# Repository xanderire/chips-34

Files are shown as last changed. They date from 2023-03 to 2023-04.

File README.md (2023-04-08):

# chips-34

Prototype, diodless pcb with minor key stagger and two thumb keys.

This started as a project to learn [Ergogen](https://github.com/ergogen/ergogen) and [KiCad](https://www.kicad.org/)

- Work-in-progress pcb that is under **100mm x 100mm** in order to facilitate a common discounted price for pcb manufactures for small pcbs.
- I do not claim this to be the most efficent or best way to build a keyboard pcb.
- This project is more to have fun and prototype different designs.
- As such I also cannot promise any files in this repo are correct and will work as production files.

---

## BOM

| Components | Amount |
| :--- | :----: |
| Arduino Pro Micro | 2 |
| TRRS-PJ-320A-dual | 2 |
| SPST Tactile Switch | 2 |
| Kailh MX Hotswap Sockets | 34 |
| MX Switches | 34 |
| MX Keycaps | 34 |

---

## Images

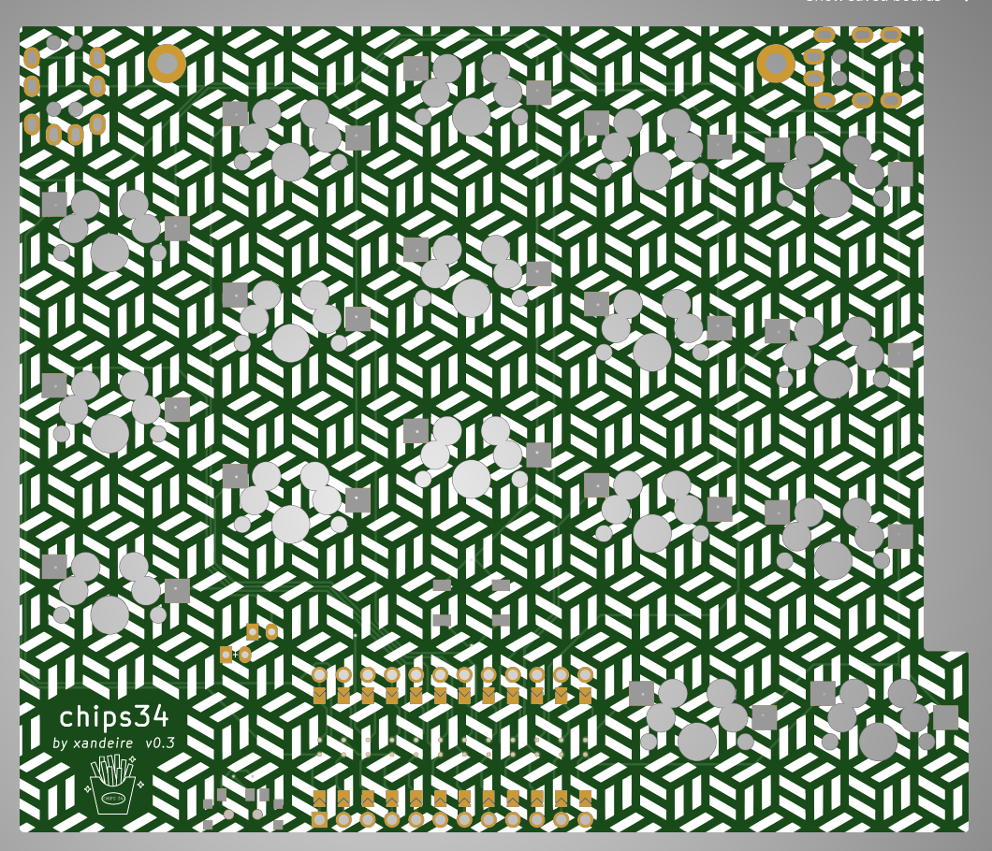
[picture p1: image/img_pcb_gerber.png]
Gerber file for pcb


[(Back to top)](#chips-34)

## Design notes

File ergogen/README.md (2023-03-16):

# Ergogen Files

These are my files for creation of pcbs via Ergogen.

They are written for Ergogen v4.0.

You can copy the contents of the `chips-34.yaml` file to [Ergogen](https://ergogen.cache.works/) to see and edit the outline visually.
 
---

## Input

- the `chips-34.yaml` can be modified and copied into **input/** in a Ergogen repository to build a new kiCad file based on the changes.

---

## Footprints

- `promicro_pretty.js` is a mcu footprint for a reversible promicro and is compatible with Ergogen v4.0.
- It should be copied into your **src/footprints** folder in a Ergogen repository in order to build the kiCad file from the `chips-34.yaml` file.
- add this line within the **module.exports** dictionary found in `index.js`:
```
promicro_pretty: require('./promicro_pretty')
```

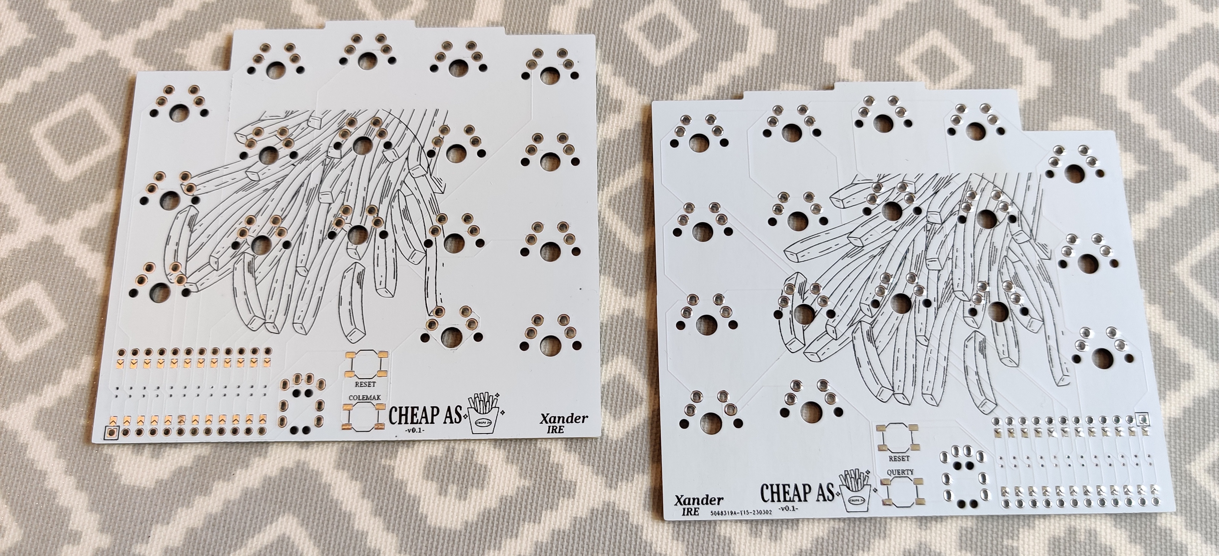
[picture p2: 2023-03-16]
image/img_pcbs.jpg

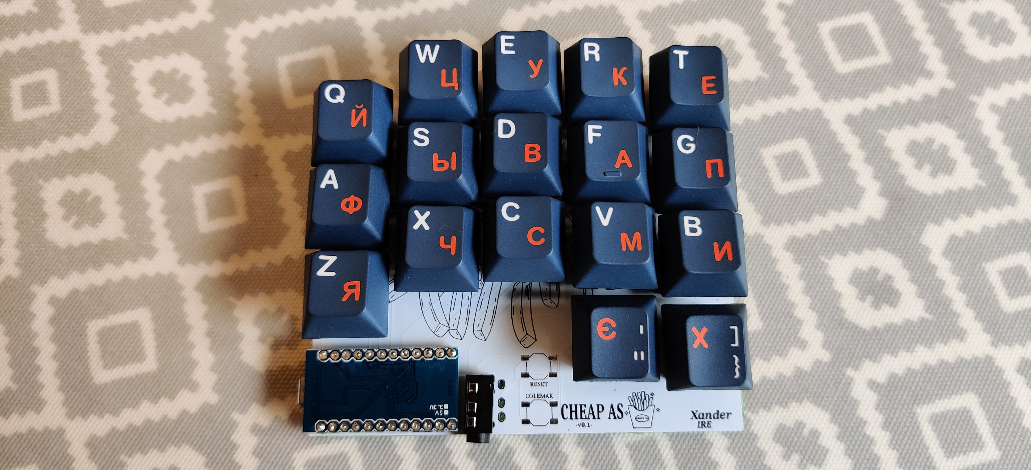
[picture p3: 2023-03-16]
image/img_built_prototype.jpg

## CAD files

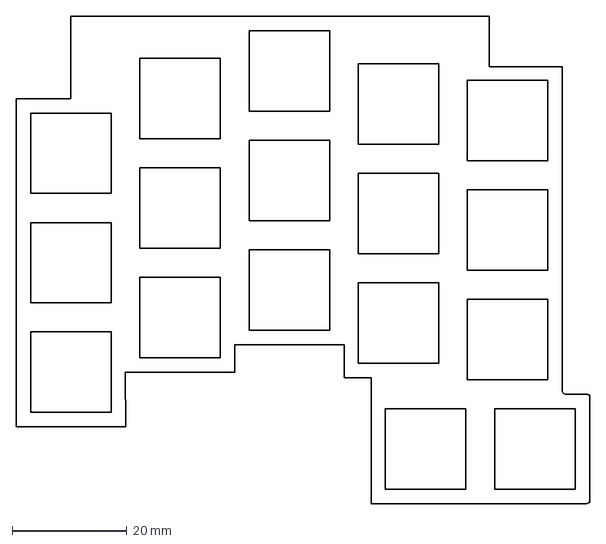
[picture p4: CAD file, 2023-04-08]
outlines/switch_plate.dxf
99.8 x 84.8 mm

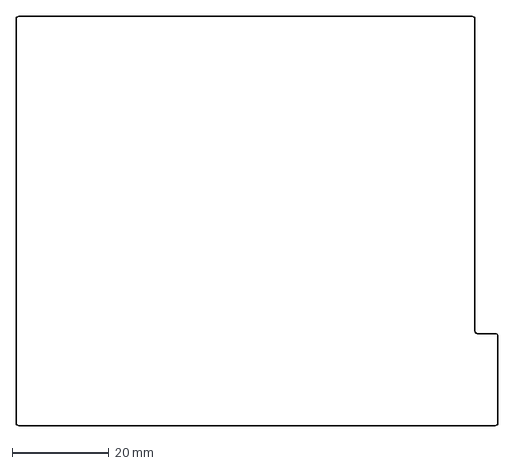
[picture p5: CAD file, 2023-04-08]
outlines/preview.dxf
99.8 x 84.8 mm

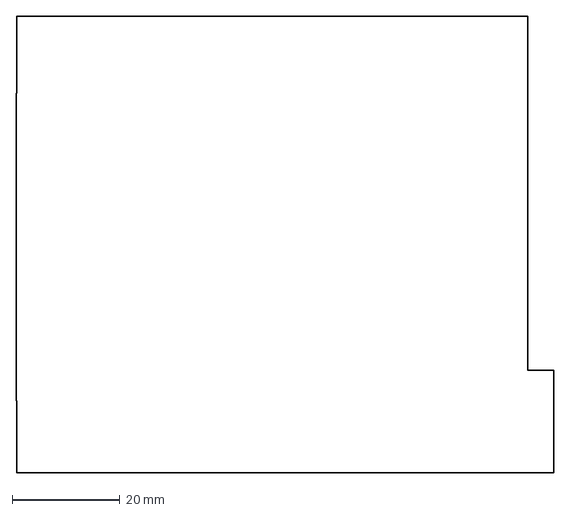
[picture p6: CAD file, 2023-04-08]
outlines/raw.dxf
99.8 x 84.8 mm

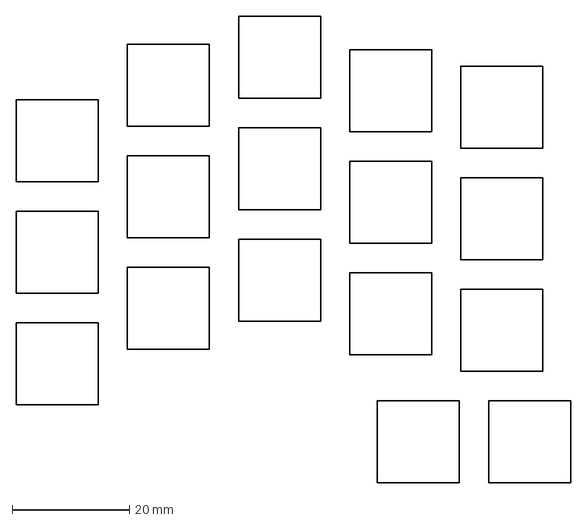
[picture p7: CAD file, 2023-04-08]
outlines/switch_cutouts.dxf
94.8 x 79.7 mm

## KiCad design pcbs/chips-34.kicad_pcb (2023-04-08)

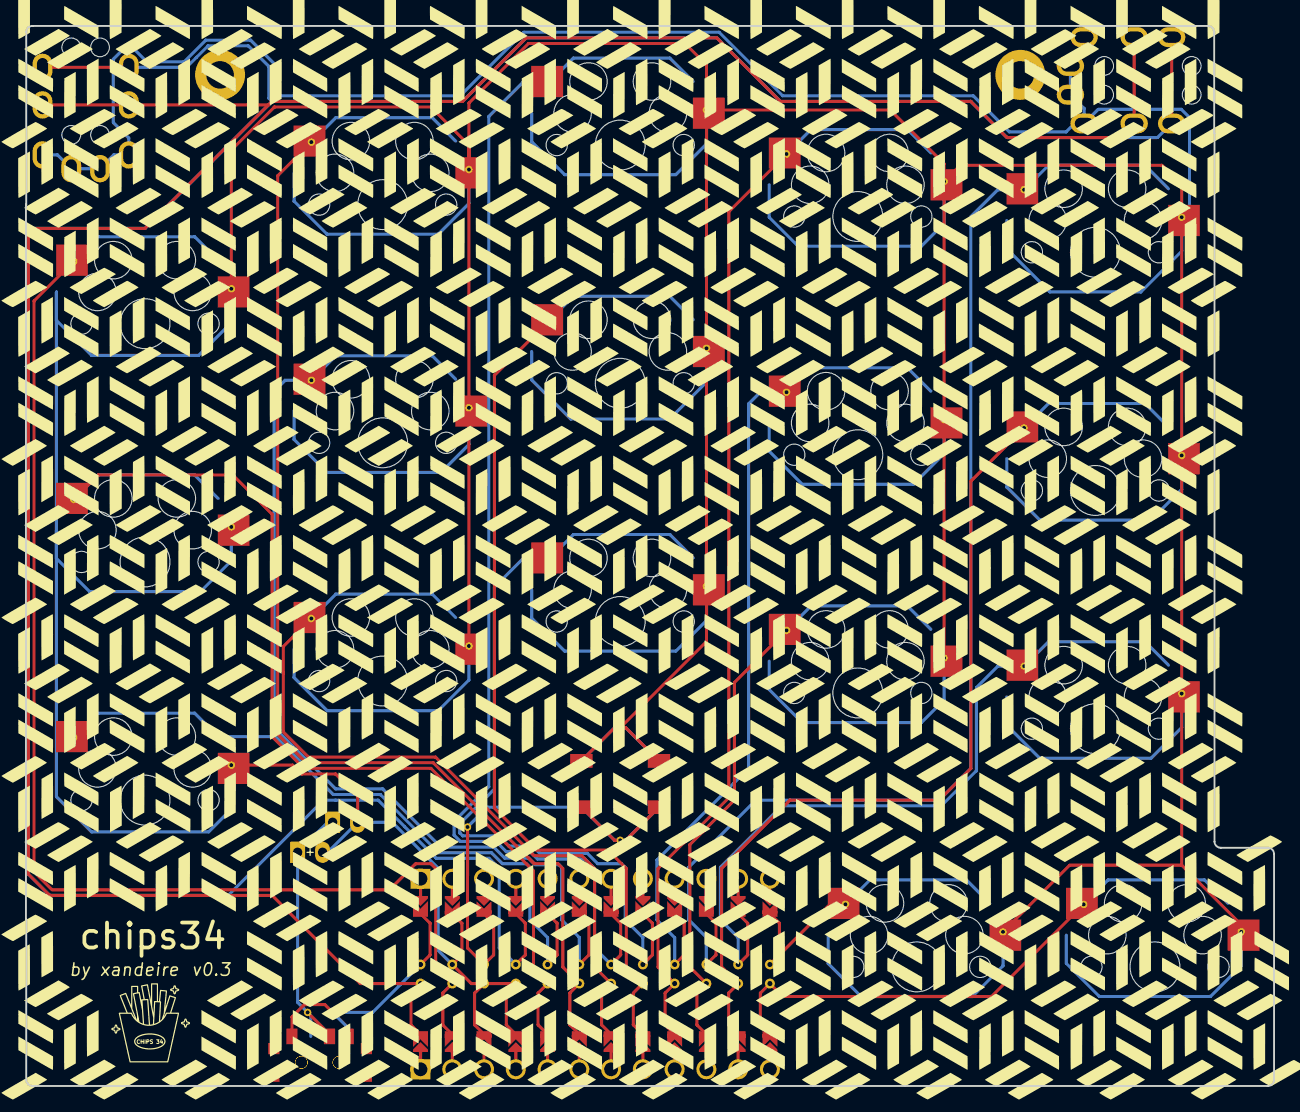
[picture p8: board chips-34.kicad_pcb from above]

Board: 2 copper layers, 99.8 x 84.8 mm, 26 parts (0 on the bottom side), 23 nets.

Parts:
B1, B2: SW_TACT_ALPS_SKQGABE010
JST1, JST2: JST_PH_S2B-PH-K_02x2.00mm_Angled
MCU1: ProMicro
S1, S2, S3, S4, S5, S6, S7, S8, S9, S10, S11, S12, S13, S14, S15, S16, S17: MX
T1, T2: SPDT_C128955
TRRS1, TRRS2: TRRS-PJ-320A-dual

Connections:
BAT: JST1.1, JST2.1, T1.2, T2.2
GND: B1.2, B2.2, JST1.2, JST2.2, MCU1.2, MCU1.21, MCU1.22, S1.1, S2.1, S3.1, S4.1, S5.1, S6.1, S7.1, S8.1, S9.1, S10.1, S11.1, S12.1, S13.1, S14.1, S15.1, S16.1, S17.1, TRRS1.1, TRRS1.2, TRRS2.1, TRRS2.2
P1: MCU1.24, TRRS1.3, TRRS2.3
RAW: MCU1.1, T1.1, T2.1
RST: B1.1, B2.1, MCU1.3
VCC: MCU1.4, TRRS1.4, TRRS2.4
matrix_index_bottom: MCU1.15, S10.2
matrix_index_home: MCU1.9, S11.2
matrix_index_top: MCU1.16, S12.2
matrix_inner_bottom: MCU1.11, S13.2
matrix_inner_home: MCU1.14, S14.2
matrix_inner_top: MCU1.10, S15.2
matrix_middle_bottom: MCU1.8, S7.2
matrix_middle_home: MCU1.17, S8.2
matrix_middle_top: MCU1.7, S9.2
matrix_pinky_bottom: MCU1.5, S1.2
matrix_pinky_home: MCU1.20, S2.2
matrix_pinky_top: MCU1.23, S3.2
matrix_ring_bottom: MCU1.18, S4.2
matrix_ring_home: MCU1.6, S5.2
matrix_ring_top: MCU1.19, S6.2
thumb_resting: MCU1.13, S16.2
thumb_squeeze: MCU1.12, S17.2

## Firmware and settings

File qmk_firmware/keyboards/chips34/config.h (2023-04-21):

// Copyright 2023 Alexander Ireland (@XanderIRE)
// SPDX-License-Identifier: GPL-2.0-or-later

#pragma once

#include "config_common.h"

#define USE_SERIAL
#define SOFT_SERIAL_PIN D3

/* key matrix size */
#define MATRIX_ROWS 8
#define MATRIX_COLS 5

#define DIRECT_PINS {{D2, D0, F6, D7, B3}, \
                     {D1, F5, C6, B1, B4}, \
                     {F4, D4, F7, E6, B2}, \
                     {NO_PIN, NO_PIN, NO_PIN, B6, B5}} 
#define DIRECT_PINS_RIGHT {{D2, D0, F6, D7, B3}, \
                     {D1, F5, C6, B1, B4}, \
                     {F4, D4, F7, E6, B2}, \
                     {NO_PIN, NO_PIN, NO_PIN, B6, B5}} 

/* Mod-tap / Layer-tap Useability Settings */
#define TAPPING_TERM 225
#define IGNORE_MOD_TAP_INTERRUPT
#define PERMISSIVE_HOLD
#define RETRO_TAPPING_PER_KEY




/*
 * Feature disable options
 *  These options are also useful to firmware size reduction.
 */

/* disable debug print */
//#define NO_DEBUG

/* disable print */
//#define NO_PRINT

/* disable action features */
//#define NO_ACTION_LAYER
//#define NO_ACTION_TAPPING
//#define NO_ACTION_ONESHOT

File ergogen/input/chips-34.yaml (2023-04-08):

# diodless, cheap columnar pcb design with pinky stagger and two thumb keys

points:
  zones:
    matrix:
      columns:
        pinky:
        ring:
          key:
            stagger: 0.5U
        middle:
          key:
            stagger: 0.25U
        index:
          key:
            stagger: -0.3U
        inner:
          key:
            stagger: -0.15U
      rows:
        bottom:
          padding: 1U
        home:
          padding: 1U
        top:
          padding: 1U
    thumb:
      anchor:
        ref: matrix_inner_bottom
        shift: [0.25U, -1U]
        rotate: 0
      columns:
        resting:
          key:
            name: thumb_resting
        squeeze:
          key:
            name: thumb_squeeze
            spread: 1U
            splay: 0
            shift: [-2U, 0]
            rotate: 0

outlines:
  raw:
    - what: rectangle
      where: true
      asym: left
      size: [1U, 1U]
      corner:
    - what: rectangle
      where: thumb_squeeze
      size: [95, 1.9U]
      adjust:
        ref: matrix_middle_bottom
        shift: [0, -U]
    - what: rectangle
      where: thumb_resting
      size: [1U, U]
      adjust:
        shift: [-0.6, 0]
    - what: rectangle
      where: matrix_middle_top
      size: [95, 1U]
  panel:
    - what: outline
      name: raw
      fillet: 0.5
  switch_cutouts:
    - what: rectangle
      where: true
      asym: left
      size: 14
      bound: false
  switch_plate:
    main:
      what: outline
      name: panel
      fillet: 0.5
    keyholes:
      what: outline
      name: switch_cutouts
      operation: subtract
    mcu_cutout:
      what: polygon
      points:
        - ref: matrix_ring_bottom
          shift: [-0.5U, 0.5U]
        - ref: matrix_ring_bottom
          shift: [0.5U, 0.5U]
        - ref: matrix_middle_bottom
          shift: [-0.5U, 0.5U]
        - ref: matrix_middle_bottom
          shift: [0.5U, 0.5U]
        - ref: matrix_middle_bottom
          shift: [0.5U, 0.2U]
        - ref: matrix_index_bottom
          shift: [-0.25U, 0.5U]
        - ref: matrix_index_bottom
          shift: [-0.25U, -0.7U]
        - ref: matrix_pinky_bottom
          shift: [-0.5U, -0.5U]
        - ref: matrix_pinky_bottom
          shift: [-0.5U, 0.5U]
        - ref: matrix_pinky_bottom
          shift: [0.5U, 0.5U]
      adjust:
          shift: [0, -1U]
      operation: subtract
    trrs_up_cutout:
      what: rectangle
      where: matrix_pinky_top
      size: [0.5U, 1U]
      adjust:
        shift: [-0.25U, 1U]
      operation: subtract
    trrs_side_cutout:
      what: rectangle
      where: matrix_inner_top
      size: [1U, 0.5U]
      adjust:
        shift: [0.33U, 0.74U]
      operation: subtract
  preview:
    [panel]

pcbs:
  chips-34:
    outlines:
      board:
        outline: preview
      keycaps:
        outline: switch_cutouts
        layer: Eco1.User
    footprints:
      mx_hotswap:
        what: mx
        where: true
        params:
          from: GND
          to: "{{name}}"
          reverse: true
          keycaps: true
          hotswap: true
      mcu:
        what: promicro_pretty
        where:
          - ref: matrix_middle_bottom
            shift: [-2, -1.48U]
            rotate: 0
        params:
          P21: matrix_pinky_bottom
          P20: matrix_ring_home
          P19: matrix_middle_top
          P18: matrix_middle_bottom        
          P15: matrix_index_home
          P14: matrix_inner_top
          P16: matrix_inner_bottom
          P10: thumb_squeeze
          # P1:
          P0: matrix_pinky_top
          P2: matrix_pinky_home
          P3: matrix_ring_top
          P4: matrix_ring_bottom
          P5: matrix_middle_home
          P6: matrix_index_top
          P7: matrix_index_bottom
          P8: matrix_inner_home
          P9: thumb_resting
      via_switch_pin:
        what: via
        where: true
        params:
          net: "{{name}}"
        adjust:
          shift: [-5.7, 5]
      via_switch_gnd:
        what: via
        where: true
        params:
          net: GND
        adjust:
          shift: [6.9, 2.8]
      trrs_side:
        what: trrs
        where:
          ref: matrix_inner_top
          shift: [9.3, 12.6]
          rotate: -90
        params:
          mirror: true
          reverse: true
          symmetric: false
          A: GND
          B: GND
          C: P1
          D: VCC
      trrs_up:
        what: trrs
        where:
          ref: matrix_pinky_top
          shift: [-3.6, 23.7]
        params:
          mirror: true
          reverse: true
          symmetric: false
          A: GND
          B: GND
          C: P1
          D: VCC
      reset_button:
        what: button
        where:
          ref: matrix_middle_bottom
          shift: [0, -13]
          rotate: 180
        params:
          from: RST
          to: GND
          side: F
      reset_button_reverse:
        what: button
        where:
          ref: matrix_middle_bottom
          shift: [0, -13]
          rotate: 180
        params:
          from: RST
          to: GND
          side: B
      via_rst:
        what: via
        adjust: 
          ref: matrix_middle_bottom
          shift: [0, -17.5]
        params: 
          net: RST
      via_rst_gnd:
        what: via
        adjust: 
          ref: matrix_middle_bottom
          shift: [0, -8.5]
        params: 
          net: GND
      powerswitch_front:
        what: slider
        where:
          ref: matrix_ring_bottom
          rotate: 180
          shift: [-5, -30.5]
        params:
          from: RAW
          to: BAT
          side: F
      powerswitch_back:
        what: slider
        where:
          ref: matrix_ring_bottom
          rotate: 180
          shift: [-5, -30.5]
        params:
          from: RAW
          to: BAT
          side: B
      via_power_raw:
        what: via
        adjust: 
          ref: matrix_ring_bottom
          shift: [-4, -26.5]
        params: 
          net: RAW
      via_power_bat:
        what: via
        adjust: 
          ref: matrix_ring_bottom
          shift: [-6, -26.5]
        params: 
          net: BAT
      bat_front:
        what: jstph
        where:
          ref: matrix_ring_bottom
          shift: [-5.8, -13.7]
        params:
          pos: BAT
          neg: GND
          side: F
      bat_back:
        what: jstph
        where:
          ref: matrix_ring_bottom
          shift: [-3, -11.3]
        params:
          pos: BAT
          neg: GND
          side: B

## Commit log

2023-03-16 adding pcb files
    [chips-34-B_Cu.gbr, chips-34-B_Mask.gbr, chips-34-B_Paste.gbr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]
2023-03-16 reorganising file structure
    [chips-34-B_Cu.gbr, chips-34-B_Mask.gbr, chips-34-B_Paste.gbr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]
2023-03-16 updating readme with bom and images
2023-03-27 Reassign serial trrs conn to correct pin
    [config.h]
2023-04-08 update switch plate cutouts
2023-04-08 update outlines with component cutouts
    [panel.dxf, preview.dxf, raw.dxf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]
2023-04-08 update kicad files to new version .3
    [chips-34-B_Cu.gbr, chips-34-B_Mask.gbr, chips-34-B_Paste.gbr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]
2023-04-08 add updated gerbers for production
    [chips-34-B_Cu.gbr, chips-34-B_Mask.gbr, chips-34-B_Paste.gbr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]
2023-04-08 remove extra kicad files
    [chips-34-design.kicad_pcb]
2023-04-08 update readme BOM for new pcb
2023-04-21 fix reversed right hand mcu pin layout
    [config.h]
